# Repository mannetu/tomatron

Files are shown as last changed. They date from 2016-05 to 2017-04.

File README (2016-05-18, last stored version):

// Software SPI (slower updates, more flexible pin options):
// pin 7 - Serial clock out (SCLK)
// pin 6 - Serial data out (DIN)
// pin 5 - Data/Command select (D/C)
// pin 4 - LCD chip select (CS)
// pin 3 - LCD reset (RST)
//Adafruit_PCD8544 display = Adafruit_PCD8544(7, 6, 5, 4, 3);

// Hardware SPI (faster, but must use certain hardware pins):
// SCK is LCD serial clock (SCLK) - this is pin 13 on Arduino Uno
// MOSI is LCD DIN - this is pin 11 on an Arduino Uno
// pin 5 - Data/Command select (D/C)
// pin 4 - LCD chip select (CS)
// pin 3 - LCD reset (RST)
Adafruit_PCD8544 display = Adafruit_PCD8544(8, 7, 6);
// Note with hardware SPI MISO and SS pins aren't used but will still be read
// and written to during SPI transfer.  Be careful sharing these pins!

#define NUMFLAKES 10
#define XPOS 0
#define YPOS 1
#define DELTAY 2

#define LOGO16_GLCD_HEIGHT 16
#define LOGO16_GLCD_WIDTH  16

static const unsigned char PROGMEM logo16_glcd_bmp[] =
{ B00000000, B00000000,
 B00000000, B00000000,
 B00000000, B00000000,
 B00000000, B00000000,
 B00000000, B00000000,
 B00000000, B00000000,
 B00000000, B00000000,
 B00000000, B00000000,
 B00000000, B00000000,
 B00000000, B00000000,
 B00000000, B00000000,
 B00000000, B00000000,
 B00000000, B00000000,
 B00000000, B00000000,
 B00000000, B00000000,
 B00000000, B00000000 };

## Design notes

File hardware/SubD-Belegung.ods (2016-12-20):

Funktion | Kabel | Klemme | Atmega Pin | SubD pin
+5V | gelb | 1 | 7/20/21 | 4
GND | orange | 2 | 8/21 | 3
Valve 1 | braun | 3 | 11 | 1
Valve 2 | rot | 4 | 12 | 2
Valve 3 | weiss | 5 | 13 | 9
Valve 4 | schwarz | 6 | 14 | 10
Valve 5 | blau | 7 | 24 | 15
Valve 6 | grau | 8 | 25 | 8
Pump | rosa | 9 | 6 | 12
Flow | hellblau | 12 | 5 | 13
 |  | 10
 |  | 11
RX | petrol |  | 2 | 14
TX | hellgrün |  | 3 | 6
Reset | violet |  | 1 | 7
Button4 | türkis? |  | 23 | 5

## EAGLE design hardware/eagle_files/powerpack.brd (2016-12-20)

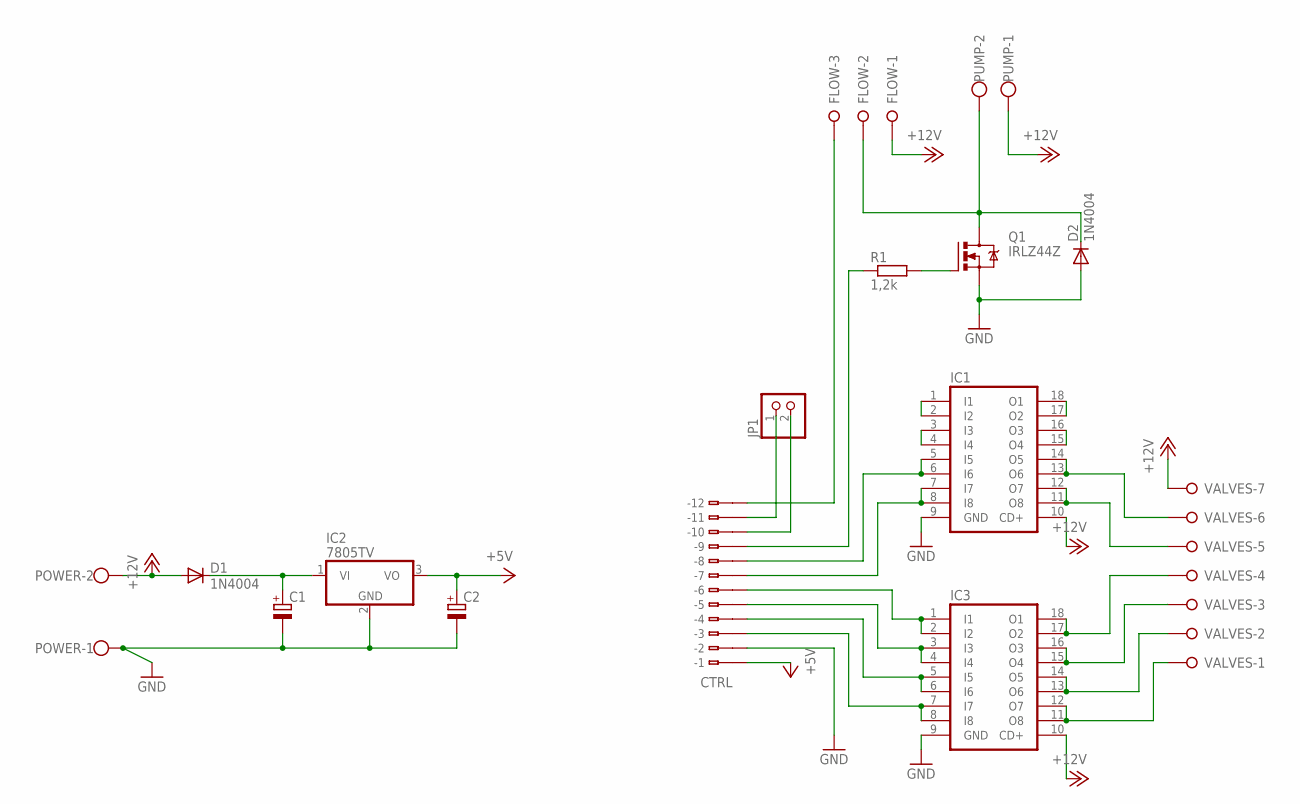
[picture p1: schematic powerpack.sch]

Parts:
C1, C2: CPOL-EUE2.5-7; E2,5-7
CTRL: 233-112
D1, D2: 1N4004; DO41-10
FLOW: W237-03P; W237-133
IC1, IC3: ULN2803A; DIL18
IC2: 7805TV; TO220V
JP1: PINHD-1X2; 1X02
POWER: W237-102
PUMP: W237-102
Q1: IRLZ44Z; TO220BH
R1: 1,2k; 0207/10
VALVES: W237-07P; W237-7P

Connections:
+5V: C2.+, CTRL.B1 (B-1), IC2.3 (VO)
+12V: D1.A, FLOW.1, IC1.10 (CD+), IC3.10 (CD+), POWER.2, PUMP.1, VALVES.7
GND: C1.-, C2.-, CTRL.B2 (B-2), D2.A, IC1.9 (GND), IC2.2 (GND), IC3.9 (GND), POWER.1, Q1.S
unnamed: C1.+, D1.C, IC2.1 (VI)
unnamed: CTRL.B12 (B-12), FLOW.3
unnamed: CTRL.B11 (B-11), JP1.1
unnamed: CTRL.B10 (B-10), JP1.2
unnamed: IC1.1 (I1), IC1.2 (I2)
unnamed: IC1.3 (I3), IC1.4 (I4)
unnamed: CTRL.B8 (B-8), IC1.5 (I5), IC1.6 (I6)
unnamed: CTRL.B7 (B-7), IC1.7 (I7), IC1.8 (I8)
unnamed: IC1.17 (O2), IC1.18 (O1)
unnamed: IC1.15 (O4), IC1.16 (O3)
unnamed: IC1.13 (O6), IC1.14 (O5), VALVES.6
unnamed: IC1.11 (O8), IC1.12 (O7), VALVES.5
unnamed: Q1.G, R1.2
unnamed: D2.C, FLOW.2, PUMP.2, Q1.D
unnamed: IC3.17 (O2), IC3.18 (O1), VALVES.4
unnamed: IC3.15 (O4), IC3.16 (O3), VALVES.3
unnamed: IC3.13 (O6), IC3.14 (O5), VALVES.2
unnamed: IC3.11 (O8), IC3.12 (O7), VALVES.1
unnamed: CTRL.B3 (B-3), IC3.7 (I7), IC3.8 (I8)
unnamed: CTRL.B4 (B-4), IC3.5 (I5), IC3.6 (I6)
unnamed: CTRL.B5 (B-5), IC3.3 (I3), IC3.4 (I4)
unnamed: CTRL.B6 (B-6), IC3.1 (I1), IC3.2 (I2)
unnamed: CTRL.B9 (B-9), R1.1

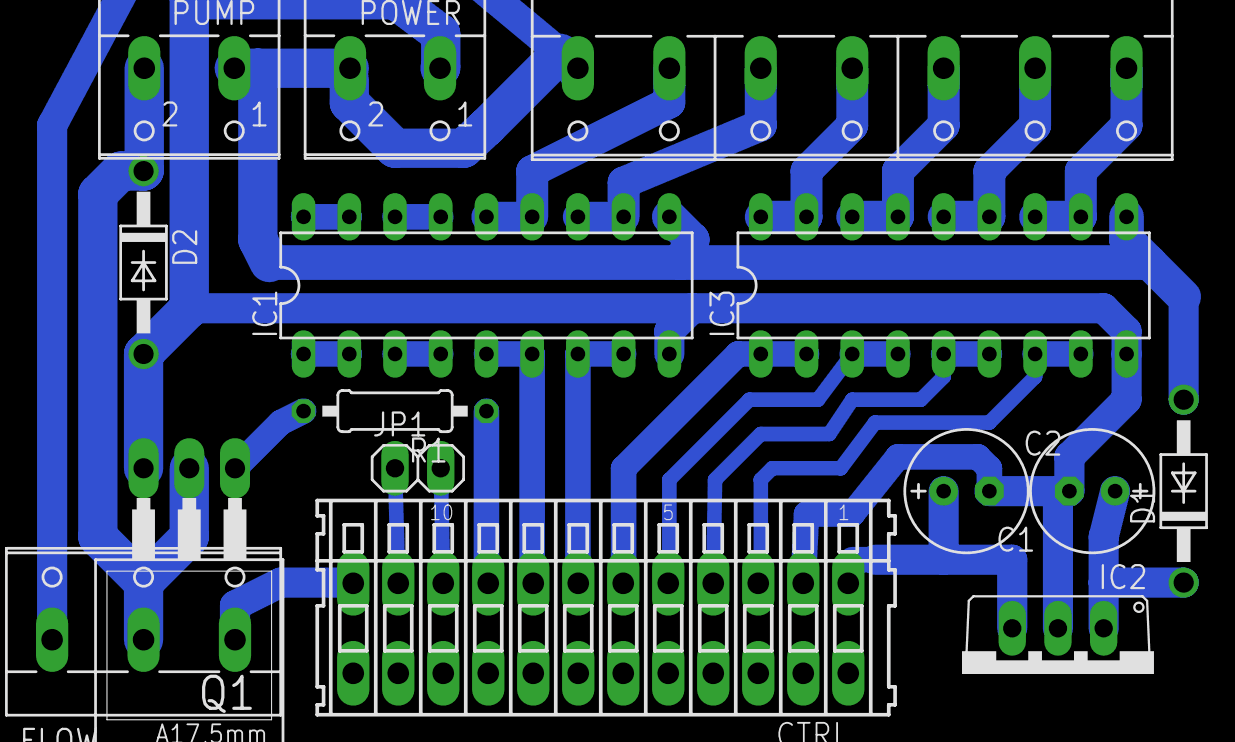
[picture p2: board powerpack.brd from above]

Board: 2 copper layers, 15 parts (0 on the bottom side), 26 nets.

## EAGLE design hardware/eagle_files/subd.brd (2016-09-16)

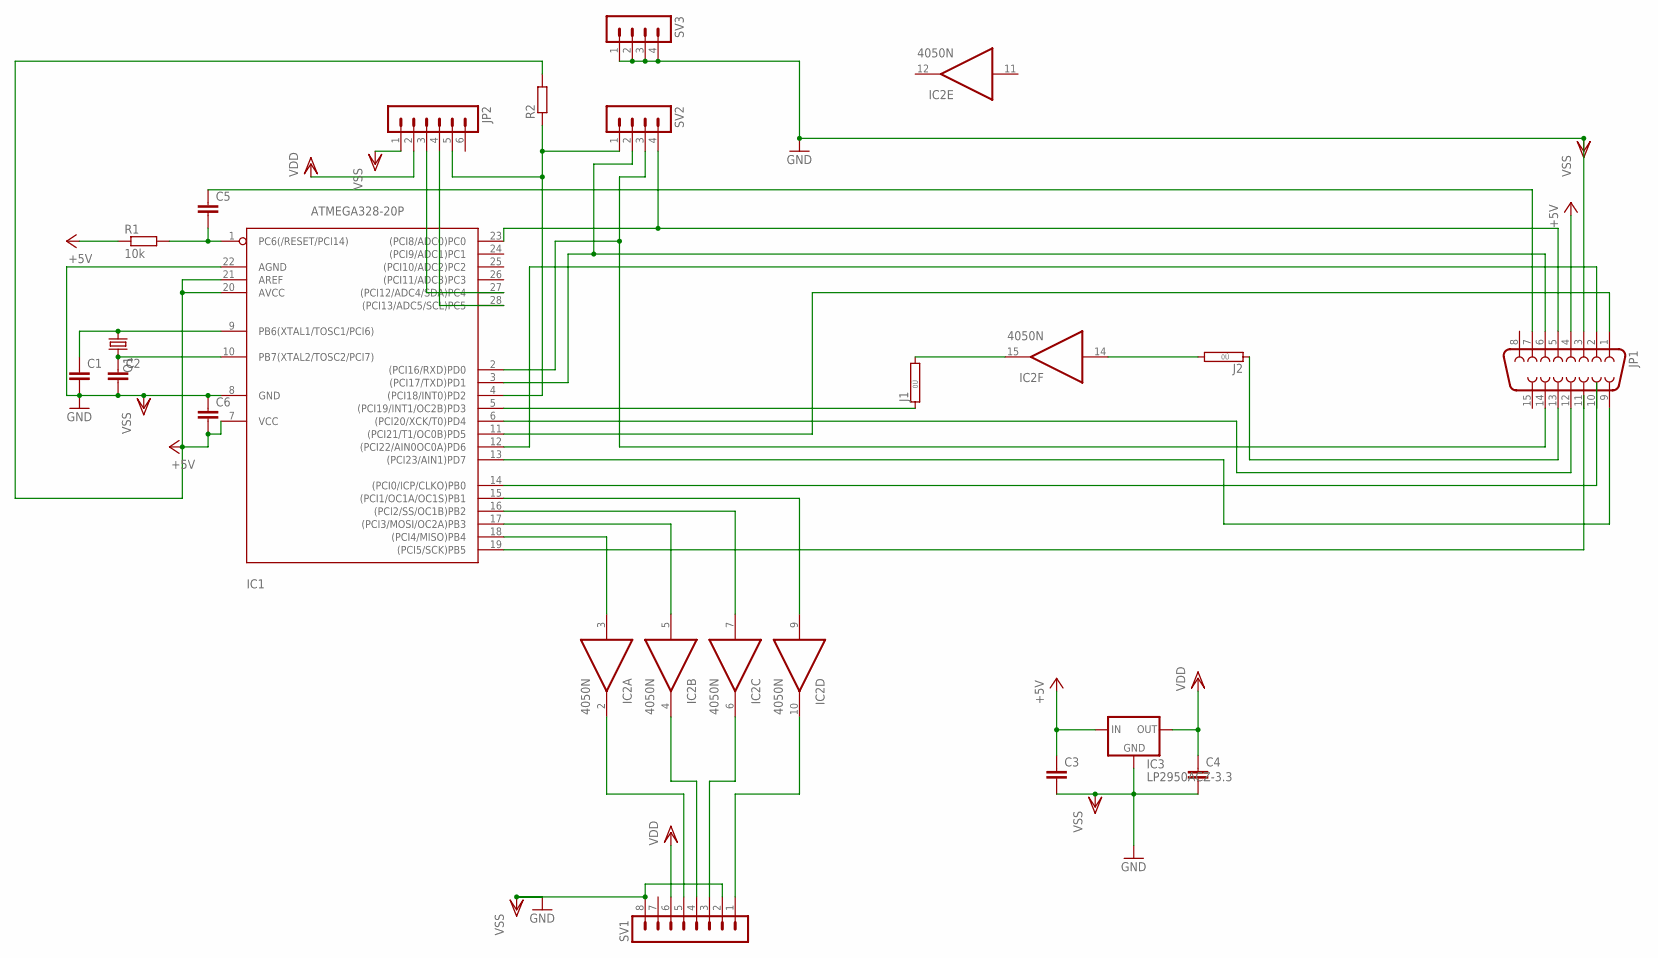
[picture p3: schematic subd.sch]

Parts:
C1, C2, C5, C6: C5/3; C5B3
C3, C4: C2.5/5; C2.5-5
IC1: ATMEGA328-20P; DIL28-3
IC2: 4050N; DIL16
IC3: LP2950ACZ-3.3; TO92
J1, J2: 0R; 0R/10
JP1: F15H
JP2: MA06-1
Q1: CRYSTALHC18U-V; HC18U-V
R1: 10k; 0207/12
R2: R-EU_0207/10; 0207/10
SV1: MA08-1
SV2, SV3: MA04-1

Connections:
+5V: C3.1, C6.2, IC1.7 (VCC), IC1.20 (AVCC), IC1.21 (AREF), IC3.3 (IN), JP1.4, R1.1, R2.2
unnamed: C1.1, IC1.9 (PB6(XTAL1/TOSC1/PCI6)), Q1.1
unnamed: C2.1, IC1.10 (PB7(XTAL2/TOSC2/PCI7)), Q1.2
unnamed: IC1.14 ((PCI0/ICP/CLKO)PB0), JP1.10
unnamed: IC1.13 ((PCI23/AIN1)PD7), JP1.9
unnamed: IC1.15 ((PCI1/OC1A/OC1S)PB1), IC2.9 (I)
unnamed: IC1.16 ((PCI2/SS/OC1B)PB2), IC2.7 (I)
unnamed: IC1.17 ((PCI3/MOSI/OC2A)PB3), IC2.5 (I)
unnamed: IC1.18 ((PCI4/MISO)PB4), IC2.3 (I)
unnamed: IC2.2 (O), SV1.5
unnamed: IC2.4 (O), SV1.4
unnamed: IC2.6 (O), SV1.3
unnamed: IC2.10 (O), SV1.1
unnamed: IC1.12 ((PCI22/AIN0OC0A)PD6), JP1.2
unnamed: IC1.11 ((PCI21/T1/OC0B)PD5), JP1.1
unnamed: IC1.6 ((PCI20/XCK/T0)PD4), JP1.12
unnamed: IC1.5 ((PCI19/INT1/OC2B)PD3), J1.1
unnamed: C5.1, JP1.7
unnamed: C5.2, IC1.1 (PC6(/RESET/PCI14)), R1.2
unnamed: IC1.27 ((PCI12/ADC4/SDA)PC4), JP2.3
unnamed: IC1.28 ((PCI13/ADC5/SCL)PC5), JP2.4
unnamed: IC1.4 ((PCI18/INT0)PD2), JP2.5, R2.1, SV2.1
unnamed: IC1.3 ((PCI17/TXD)PD1), JP1.6, SV2.2
unnamed: IC1.2 ((PCI16/RXD)PD0), JP1.14, SV2.3
unnamed: IC2.14 (I), J2.2
unnamed: IC1.23 ((PCI8/ADC0)PC0), JP1.5, SV2.4
unnamed: IC2.15 (O), J1.2
unnamed: J2.1, JP1.13
unnamed: IC1.19 ((PCI5/SCK)PB5), JP1.11
VDD: C4.1, IC2.1 (VDD), IC3.1 (OUT), JP2.2, SV1.6
VSS: C1.2, C2.2, C3.2, C4.2, C6.1, IC1.8 (GND), IC1.22 (AGND), IC2.8 (VSS), IC3.2 (GND), JP1.3, JP2.1, SV1.2, SV1.8, SV3.1, SV3.2, SV3.3, SV3.4

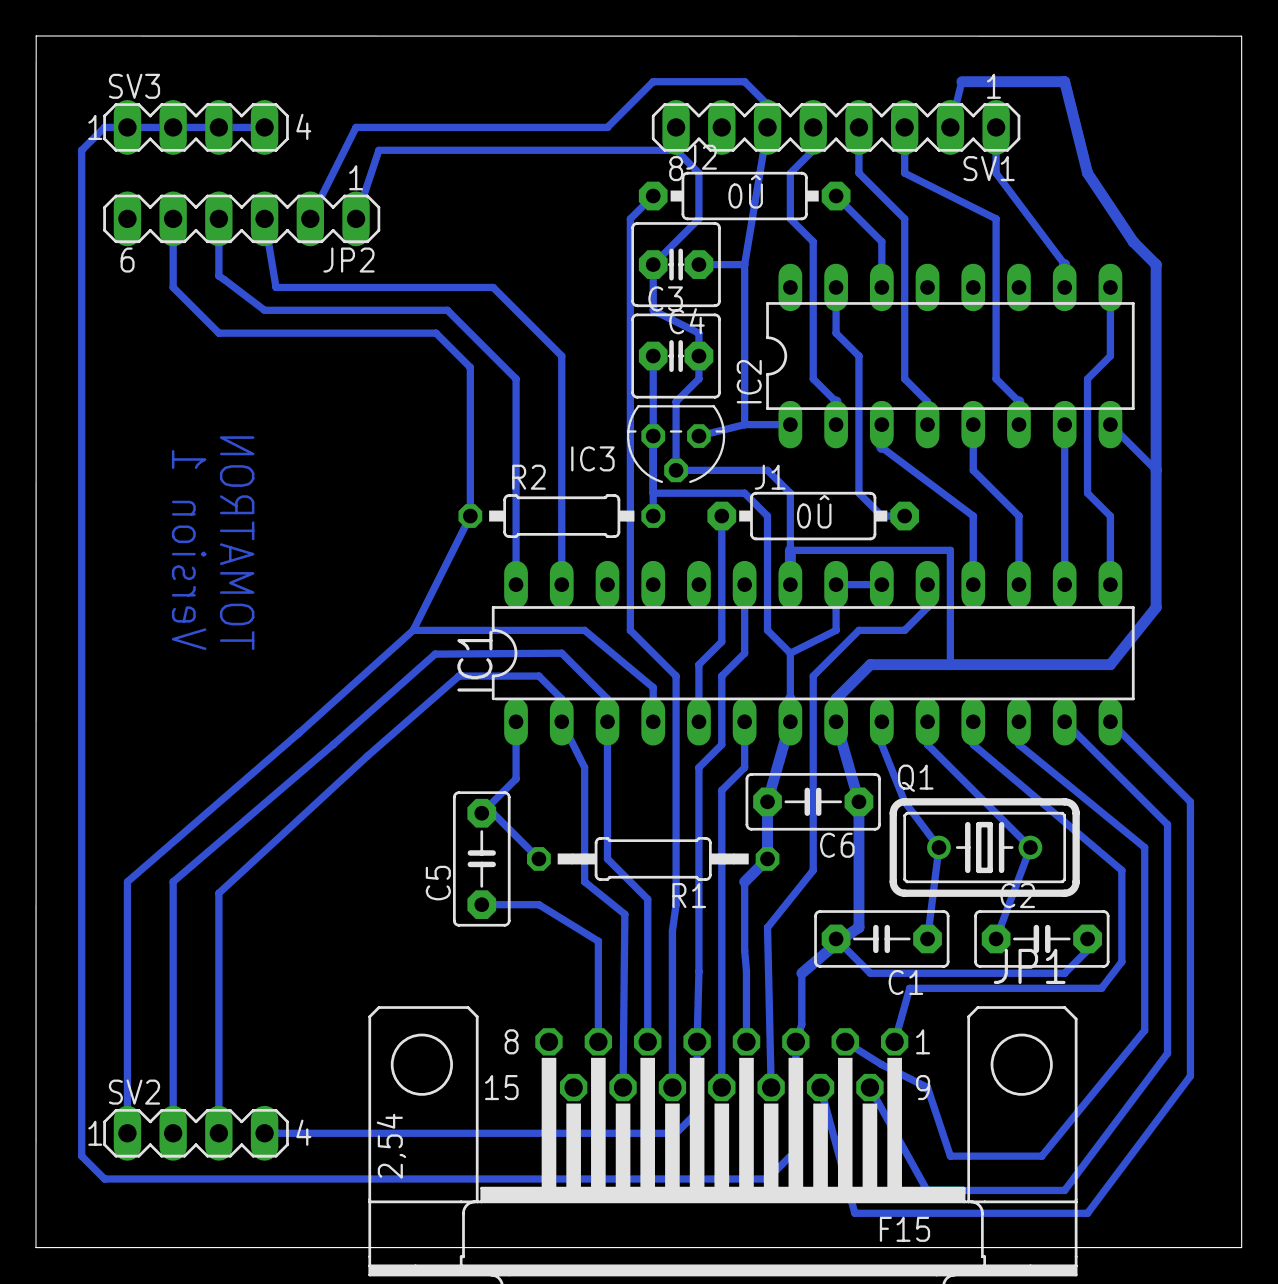
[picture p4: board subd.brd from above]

Board: 2 copper layers, 67.0 x 67.3 mm, 19 parts (0 on the bottom side), 31 nets.

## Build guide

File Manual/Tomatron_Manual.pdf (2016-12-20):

# T O M A T R O N

## Installation

&

## Bedienungsanleitung

Version 1.0

Das Kleingedruckte:
Der Hersteller übernimmt keine Haftung für vertrocknete Tomaten, Paprika, etc.

## Installation der Schalteinheit

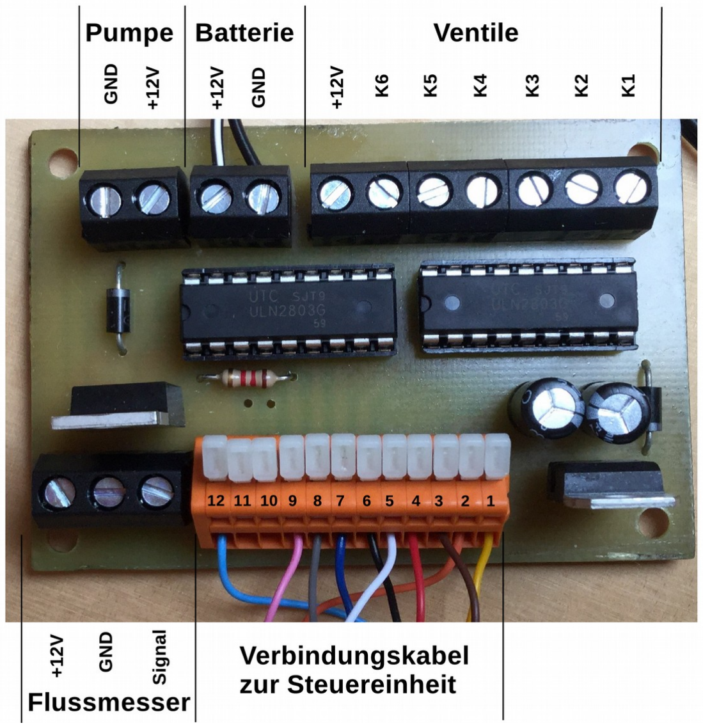
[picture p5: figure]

1. Pumpe anklemmen. Maximale Stromaufnahme der Pumpe ist xA.
2. Batterie über beigelegte Sicherung (xA) anklemmen. Auf Polung achten!
3. Kabels zur Steuereinheit an der orangen Klemmleiste nach Farben anklemmen:
Funktion | Litzenfarbe | Klemme
+5V | gelb | 1
GND | orange | 2
Ventil 1 | braun | 3
Ventil 2 | rot | 4
Ventil 3 | weiss | 5
Ventil 4 | schwarz | 6
Ventil 5 | dunkelblau | 7
Ventil 6 | grau | 8
Pumpe | rosa | 9
nicht belegt | | 10
nicht belegt | | 11
Flowmeter Signal | hellblau | 12
4. Ventile an gemeinsame Klemme für +12V und Klemmen K1 bis K6 anschliessen. Maximale Stromaufnahme pro Ventil ist xA.
5. Flussmessers an +12V (rotes Kabel), GND (schwarzes Kabel) und Signal (gelbes Kabel) anklemmen.

## Installation der Bedieneinheit und Bedienelemente

## Inbetriebnahme

Kalibrierung des Flussmessers
Zur genauen Dosierung muss der Flussmesser bei Inbetriebnahme kalibriert werden. Hierfür muss die Taste MENU während des Anklemmens der Stromversorgung kurzzeitig gehalten werden. Nach einem weiteren Betätigen der Taste MENU werden über Ventil 1 circa 10 L Wasser dosiert. Die genaue Menge ist im Anschluss auszuwiegen und mit den Tasten + und − einzustellen. Die Kalibrierung wird mit der Taste MENU abgeschlossen.

Einstellen der Uhrzeit
Zum Einstellen der Uhrzeit nach muss die Taste MENU wiederholt gedrückt werden bis die Anzeige der Uhrzeit dunkel hinterlegt angezeigt wird.
Die Uhrzeit ist nun durch Halten der Tasten + und − einzustellen.
Wenn die gewünschte Uhrzeit angezeigt wird, kann die Einstellung mit einem weiteren Betätigen der Taste MENU abgeschlossen werden oder gewartet werden bis die Anzeige einigen Sekunden von selbst in den Normalmodus zurückspringt.

## Einstellungen

Einstellen der Giessmengen
Zum Einstellen der Giessmengen muss die Taste MENU gedrückt werden bis der jeweilige Giesskanal dunkel hinterlegt angezeigt wird. Die Menge ist nun durch Halten der Tasten + und − einzustellen. Wenn die gewünschte Uhrzeit angezeigt wird, kann mit einem weiteren Betätigen der Taste MENU zum nächsten Kanal gewechselt werden. Sind alle Einstellungen getätigt springt die Anzeige einigen Sekunden von selbst in den Normalmodus zurück. Einstellen der Giesszeit
Zum Einstellen der Giesszeit nach muss die Taste MENU wiederholt gedrückt werden bis die Anzeige der Giesszeit dunkel hinterlegt angezeigt wird.
Die Giesszeit ist nun durch Halten der Tasten + und − einzustellen.
Wenn die gewünschte Giesszeit angezeigt wird, kann mit einem weiteren Betätigen der Taste MENU zur Einstellung des Giessfaktors gewechselt werden. Ohne Tastendruck springt die Anzeige nach ein einigen Sekunden von selbst in den Normalmodus zurück.

Einstellen des Giesskoeffizient f
Die Steuereinheit zeichnet von 8 Uhr morgens bis zur eingestellten Giesszeit minütlich die Temperatur auf und bildet hieraus den Tagesmittelwert der Temperatur. Dieser wird aktuell im Display angezeigt.
In Abhängigkeit des errechneten Temperaturmittelwertes und eines einzustellenden Giesskoeffizienten f werden die vorgegebnen Giessmengen pro Kanal mit einem Giessfaktor multipliziert der sich aus dem Diagramm ergibt. Zum Einstellen des Giesskoeffizients f muss die Taste MENU gedrückt werden bis das Feld dunkel hinterlegt angezeigt wird. Der Wert ist nun durch Halten der Tasten + und − einzustellen. Die Anzeige springt ohne Tastendruck nach einigen Sekunden von selbst in den Normalmodus zurück.

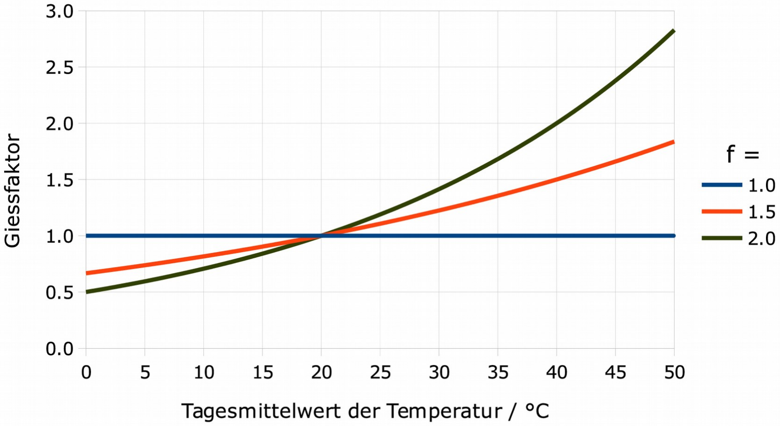
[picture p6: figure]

Beispiele: Bei einem Tagesmittelwert von 30 °C und f = 2.0 wird das 1,4-fache der voreingestellten Mengen dosiert. Bei einem Tagesmittelwert von 40 °C und f = 1,5 wird das 1,5-fache dosiert.

Funktion Kabel | Klemme Atmega Pin SubD pin
+5V | gelb | 1 | 7/20/21 | 4
GND | orange | 2 | 8/21 | 3
Valve 1 | braun | 3 | 11 | 1
Valve 2 | rot | 4 | 12 | 2
Valve 3 | weiss | 5 | 13 | 9
Valve 4 | schwarz | 6 | 14 | 10
Valve 5 | blau | 7 | 24 | 15
Valve 6 | grau | 8 | 25 | 8
Pump | rosa | 9 | 6 | 12
Flow | hellblau | 12 | 5 | 13
| | 10
| | 11
RX | petrol | | 2 | 14
TX | hellgrün | | 3 | 6
Reset | violet | | 1 | 7
Button4 | türkis? | | 23 | 5

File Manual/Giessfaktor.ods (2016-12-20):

Temperatur | 1.0 | 1.5 | 2.0
0 | 1.0 | 0.7 | 0.50
1 | 1.0 | 0.7 | 0.52
2 | 1.0 | 0.7 | 0.54
3 | 1.0 | 0.7 | 0.55
4 | 1.0 | 0.7 | 0.57
5 | 1.0 | 0.7 | 0.59
6 | 1.0 | 0.8 | 0.62
7 | 1.0 | 0.8 | 0.64
8 | 1.0 | 0.8 | 0.66
9 | 1.0 | 0.8 | 0.68
10 | 1.0 | 0.8 | 0.71
11 | 1.0 | 0.8 | 0.73
12 | 1.0 | 0.9 | 0.76
13 | 1.0 | 0.9 | 0.78
14 | 1.0 | 0.9 | 0.81
15 | 1.0 | 0.9 | 0.84
16 | 1.0 | 0.9 | 0.87
17 | 1.0 | 0.9 | 0.90
18 | 1.0 | 1.0 | 0.93
19 | 1.0 | 1.0 | 0.97
20 | 1.0 | 1.0 | 1.00
21 | 1.0 | 1.0 | 1.04
22 | 1.0 | 1.0 | 1.07
23 | 1.0 | 1.1 | 1.11
24 | 1.0 | 1.1 | 1.15
25 | 1.0 | 1.1 | 1.19
26 | 1.0 | 1.1 | 1.23
27 | 1.0 | 1.2 | 1.27
28 | 1.0 | 1.2 | 1.32
29 | 1.0 | 1.2 | 1.37
30 | 1.0 | 1.2 | 1.41
31 | 1.0 | 1.2 | 1.46
32 | 1.0 | 1.3 | 1.52
33 | 1.0 | 1.3 | 1.57
34 | 1.0 | 1.3 | 1.62
35 | 1.0 | 1.4 | 1.68
36 | 1.0 | 1.4 | 1.74
37 | 1.0 | 1.4 | 1.80
38 | 1.0 | 1.4 | 1.87
39 | 1.0 | 1.5 | 1.93
40 | 1.0 | 1.5 | 2.00
41 | 1.0 | 1.5 | 2.07
42 | 1.0 | 1.6 | 2.14
43 | 1.0 | 1.6 | 2.22
44 | 1.0 | 1.6 | 2.30
45 | 1.0 | 1.7 | 2.38
46 | 1.0 | 1.7 | 2.46
47 | 1.0 | 1.7 | 2.55
48 | 1.0 | 1.8 | 2.64
49 | 1.0 | 1.8 | 2.73
50 | 1.0 | 1.8 | 2.83

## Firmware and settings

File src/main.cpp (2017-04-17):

/***********************************************
*  Tomatron v2.0
*
*
***********************************************/

#include <Arduino.h>
#include <EEPROM.h>
#include <Time.h>
#include <avr/wdt.h>  // Watchdog-Timer
#include <avr/sleep.h>
#include <avr/power.h>
#include <Wire.h>
#include <DS3232RTC.h>
#include <Adafruit_GFX.h>
#include <Adafruit_PCD8544.h>
#include "water.h"

//---------------------------------------------------------
// System Setup
//---------------------------------------------------------

#define CHANNEL 6  // Number of water channels

// Giessflag
enum giessFlag {
  CTRL_SLEEP = -3,
  CTRL_SET   = -2,
  CTRL_IDLE  = -1,
  CTRL_ACT   =  0  // 1, 2, 3
};

enum timerFlag {
  OFF,
  ON
} timer;

struct s_giess {
  int    flag     = -1;
  long   lastCall =  0;
  time_t time;
} giess;

//---------------------------------------------------------
// Display
//---------------------------------------------------------
// Nokia 5110 Adafruit Library
// Software SPI (slower updates, more flexible pin options):
// pin 12 - Serial clock out (SCLK)
// pin 11 - Serial data out (DIN)
// pin 10 - Data/Command select (D/C)
// GND    - LCD chip select (CS)
// pin 9 - LCD reset (RST)

Adafruit_PCD8544 display = Adafruit_PCD8544(12, 11, 10, 9);
#define DISPLAY_UPDATE 250  // Display update rate (milliseconds)

//---------------------------------------------------------
// Buttons
//---------------------------------------------------------
const byte pinUpBtn =     0;   // Up-Button, ATmega pin 2
const byte pinDownBtn =   A0;   // Down-Button, ATmega pin 3
const byte pinEnterBtn =  2;   // Enter-Button, Interupt 0, ATmega pin 4
const byte pinManualBtn = 1; // Manual-Button, ATmega pin 23

unsigned int btnDelay =   200; // Debounce delay

//---------------------------------------------------------
// Objects
//---------------------------------------------------------
Flowmeter flow(3); // Interupt 1 -> Pin 3 must not be changed! // ATmega pin 5

Magnetvalves valve[CHANNEL] =
{  // 8 characters max.
  Magnetvalves(5,  "Tom1  "),  // ATmega pin 11
  Magnetvalves(6,  "Tom2  "),  // ATmega pin 12
  Magnetvalves(7,  "Tom3  "),  // ATmega pin 13
  Magnetvalves(8,  "Pap1  "),  // ATmega pin 14
  Magnetvalves(A1, "Pap2  "),  // ATmega pin 24
  Magnetvalves(A2, "Gur1  ")   // ATmega pin 25
};

Pump pump(4); // ATmega pin 6

Thermocontrol thermo(8); // Daytime hour to start temperature averaging

volatile boolean alarmIsrWasCalled = true;

//---------------------------------------------------------
// Function prototypes
//---------------------------------------------------------

int   checkGiessen(void);
void  giessRoutine(void);
void  manualGiess(int);
void  statusDisplay(int, int);

void  interruptPulse(void);

void  setParameters(void);
void  writeParameters();

void  btnInterruptSleep(void);
void  enterSleep(void);

void  calibration();
void  calibrationDoseDisplay(int);
void  calibrationDisplay(double);


//-------------------------------------------------------------------
//-------------------------------------------------------------------
// SETUP
//-------------------------------------------------------------------
void setup()
{
/*** ONLY FOR INITIAL EEPROM AND RTC PROGRAMMING *******************
  // Giesstime
    setTime(18, 30, 00, 01, 05, 16); // hour, min, sec, day, month, year
    RTC.set(now());
    giess.time = now() + 3600;
    int eepromAdress = 0;
    EEPROM.put(0, giess.time);
    eepromAdress += sizeof(time_t);

  // Flow Calibration Factor
      EEPROM.put(eepromAdress, 480); // Datasheet says 480 Pulses/L
      eepromAdress += sizeof(int);

  // thermoCoeff
      float thermoCoeff = 1.5;
      EEPROM.put(eepromAdress, thermoCoeff);
********************************************************************/

  // Power management
  power_adc_disable();
  power_spi_disable();
  power_timer1_disable();
  power_timer2_disable();

  // Setup the Watchdog Timer
  wdt_enable(WDTO_8S);

  // Setup LCD display
  display.begin(); // init done
  display.setContrast(50);
  display.setRotation(2);
  display.setTextSize(1);
  display.setTextColor(BLACK);
  delay(1000);

  // Set time and RTC options
  while (RTC.get() == 0);
  setTime(RTC.get());   // the function to get the time from the RTC

  /* Set RTC alarm to wake-up microcontroller every minute
  * Alarm pin of RTC is attached to Pin 2 (EnterButton)  */
  RTC.squareWave(SQWAVE_NONE);
  RTC.alarm(ALARM_1);
  RTC.alarmInterrupt(ALARM_1, false);
  RTC.setAlarm(ALM2_EVERY_MINUTE, 1, 1, 1, 1);
  RTC.alarm(ALARM_2);
  RTC.alarmInterrupt(ALARM_2, true);

  // Set pin configuration for buttons
  pinMode(pinEnterBtn, INPUT);   //external pull-up resistor required due to interrupt function!!
  pinMode(pinUpBtn, INPUT_PULLUP);
  pinMode(pinDownBtn, INPUT_PULLUP);
  pinMode(pinManualBtn, INPUT_PULLUP);
  flow.resetFlowMeter();

  // Read giessTime from EEPROM
  int eeAdress = 0;
  EEPROM.get(eeAdress, giess.time);
  eeAdress += sizeof(time_t); // Move write position to calibration factor

  // Initialize GiessFlag
  giess.flag = CTRL_IDLE;
  timer = OFF;

  // Read calibration factor from EEPROM
  int cf;
  EEPROM.get(eeAdress, cf);
  flow.setCalibrationFactor(cf);
  eeAdress += sizeof(int); // Move write position to temperature factor

  // Read temperature factor factor from EEPROM
  float tf;
  EEPROM.get(eeAdress, tf);
  thermo.SetTempCoeff(tf);
  eeAdress += sizeof(float); // Move write position to volume targets

  // Read volume targets from EEPROM
  int vol;
  for (byte i = 0; i < (CHANNEL); i++) {
    EEPROM.get(eeAdress, vol);  //
    eeAdress += sizeof(int); // Set position to next vol target
    valve[i].setVolumeTarget(vol);
  }

  // If Enter is pressed at boot, enter calibration mode
  if (digitalRead(pinEnterBtn) == LOW) {
    display.clearDisplay();
    display.display();
    delay(2000);
    calibration();
  }
  statusDisplay(-1, -1);
}


//--------------------------------------------------------------
// Function name: loop()
//--------------------------------------------------------------
void loop()
{
  // If nothing happens
  if(giess.flag == CTRL_IDLE)
  {
    // MCU enter sleep
    statusDisplay(CTRL_SLEEP, -1);
    wdt_disable();
    enterSleep();

    // Continue after wake-up
    wdt_enable(WDTO_8S); // Enable Watchdog-Timer
    setTime(RTC.get()); // Update MCU time from RTC
    if (hour() > (thermo.GetLowerAveragingHour()-1) &&
        (hour() < hour(giess.time) || (hour() == hour(giess.time) &&
          minute() < minute(giess.time))))
    {
      thermo.AddTempReading(RTC.temperature()/float(4.0)); // Temperature measurement
    }
    statusDisplay(CTRL_IDLE, -1);
  }

  // Reset RTC alarm
  if (alarmIsrWasCalled)
  {
    RTC.alarm(ALARM_2);
    alarmIsrWasCalled = false;
  }

  // Check if it is time for giessing */
  if (timer == ON && giess.flag == CTRL_IDLE)
  {
    giess.flag = checkGiessen();
  }

  // Update Display every DISPLAY_UPDATE ms*/
  if ((millis() - giess.lastCall > DISPLAY_UPDATE))
  {
    statusDisplay(giess.flag, -1);
    giess.lastCall = millis();
  }

  // If giessing, then check progress */
  if (giess.flag > CTRL_IDLE) // that is active channel 0, 1, 2, or 3
  {
    valve[giess.flag].setGiessFactor(thermo.GetGiessFactor());
    giessRoutine();
  }

  // On enter btn press, start mode to set time, giessTime and target volumes */
  if (digitalRead(pinEnterBtn) == 0)
  {
    RTC.alarmInterrupt(ALARM_2, false);
    setParameters();
    if (giess.flag == CTRL_IDLE)
    {
      RTC.alarm(ALARM_2);
      RTC.alarmInterrupt(ALARM_2, true);
    }
  }

  wdt_reset();
}


//--------------------------------------------------------------
// Function name: checkGiessen
//
// checks if it is time for giessen
//--------------------------------------------------------------
int checkGiessen()
{
  if ((hour(giess.time) == hour()) && (minute(giess.time) == minute()))
  {
    flow.resetFlowMeter();
    RTC.alarmInterrupt(ALARM_2, false);
    return CTRL_ACT;
  }
  return CTRL_IDLE;
}


//--------------------------------------------------------------
// Function name: giessRoutine
//--------------------------------------------------------------
void giessRoutine()
{
  if (pump.start()) delay(1000); // wait for 2s if pump had to be started

  valve[giess.flag].setCurrentVolume(flow.getVolume());

  if (valve[giess.flag].dosing() == 0)
  {
    flow.resetFlowMeter();
    giess.flag++; delay(100);
  }

  if (giess.flag > CHANNEL-1)
  {
    pump.stop();
    thermo.ResetAverage();
    giess.flag = CTRL_IDLE;
    RTC.alarm(ALARM_2);
    RTC.alarmInterrupt(ALARM_2, true);
  }
}

//--------------------------------------------------------------
// Function name: manualGiess
//--------------------------------------------------------------
void manualGiess(int ch)
{
  pump.start();
  delay(500);
  giess.flag = ch;
  flow.resetFlowMeter();
  valve[ch].open();
  while (digitalRead(pinManualBtn) != 0 && digitalRead(pinEnterBtn) != 0)
  {
    valve[giess.flag].setCurrentVolume(flow.getVolume());
    if ((millis() - giess.lastCall > DISPLAY_UPDATE))
    {
      statusDisplay(giess.flag, -5);
      giess.lastCall = millis();
    }
    wdt_reset();
  }
  valve[ch].close();
  pump.stop();
  giess.flag = CTRL_IDLE;

  // Show instructions on display
  display.clearDisplay();
  display.setCursor(14,6);
  display.print(valve[ch].getPlantName());
  display.setCursor(44,6);
  display.print(flow.getVolume(), 0);
  display.println(" L");
  display.setCursor(0,17);
  display.println("  Neue Menge ");
  display.println(" uebernehmen?");
  display.setCursor(0,36);
  display.println("   +/- = ja");
  display.display();

  delay(3*btnDelay);

  long lastActivity;
  lastActivity = millis();

  while (digitalRead(pinEnterBtn) != 0 && digitalRead(pinManualBtn) != 0)
  {
    if (digitalRead(pinUpBtn) == 0 || digitalRead(pinDownBtn) == 0)
    {
      valve[ch].setVolumeTarget(flow.getVolume());
      wdt_reset();
      writeParameters();
      delay(btnDelay);
      return;
    }
    wdt_reset();
    if (millis() - lastActivity > 5000) return;
  }
  delay(btnDelay);
  return;
}

//--------------------------------------------------------------
// Status Display
//--------------------------------------------------------------
void statusDisplay(int gf, int ch)
{
  static byte blink_flag = 1;
  display.clearDisplay();
  display.setCursor(0, 0);

  //---------------------------------------------------
  // Display if nothing is active or parameter set mode

  if (gf < 0)    //  -1 or -2
  {
    if (gf == -2 && ch == -2) display.setTextColor(WHITE, BLACK);

    // Draw grid
    display.drawFastHLine(0, 9, 85, BLACK);
    display.drawFastHLine(41, 30, 43, BLACK);
    display.drawFastVLine(40, 0, 48, BLACK);

    // Print current time
    if(hour() < 10) display.print(' ');
    display.print(hour());
    display.print(":");
    if(minute() < 10) display.print('0');
    display.print(minute());
    display.setTextColor(BLACK, WHITE);

    // Print giessFactor
    display.setCursor(47, 33);
    if (gf == -2 && ch == -3)
    {
      display.setTextColor(WHITE, BLACK);
      display.print("f");
      display.print(thermo.GetTempCoeff(), 1);
      display.setTextColor(BLACK, WHITE);
    }
    else
    {
      display.print("x");
      display.print(thermo.GetGiessFactor(), 1);
    }

    // Print average temperature
    display.setCursor(47, 41);
    if (thermo.GetTempAverage() > 0)
    {
      display.print(thermo.GetTempAverage(), 1);
    }
    else
    {
      display.print("---");
    }
    display.print("C");

    // Print giess time
    display.setCursor(44, 0);
    if (timer == ON)
    {
      if (gf == -2 && ch == -1) display.setTextColor(WHITE, BLACK);
      display.print("T ");
      display.setCursor(52, 0);
      if(hour(giess.time) < 10) display.print(' ');
      display.print(hour(giess.time));
      display.print(":");
      if(minute(giess.time) < 10) display.print('0');
      display.print(minute(giess.time));
      display.setTextColor(BLACK, WHITE);
    }
    else
    {
      if (gf == -2 && ch == -1) display.setTextColor(WHITE, BLACK);
      display.print("T aus");
      display.setTextColor(BLACK, WHITE);
    }

    // Print channels, left column
    for (int i = 0; i < 4; i++)
    {
      display.setCursor(0, (8*i + 13));
      if (gf == -2 && i == ch) display.setTextColor(WHITE, BLACK);
      display.print(valve[i].getPlantName());
      display.setCursor(26, (8*i + 13));
      if (valve[i].readVolumeTarget()<10) display.print(" ");
      display.println(valve[i].readVolumeTarget());
      display.setTextColor(BLACK, WHITE);
    }

    // Print channels, right column
    for (int i = 4; i < CHANNEL; i++)
    {
      display.setCursor(44, (8*(i-4) + 13));
      if (gf == -2 && i == ch) display.setTextColor(WHITE, BLACK);
      display.print(valve[i].getPlantName());
      display.setCursor(70, (8 *(i-4) + 13));
      if (valve[i].readVolumeTarget()<10) display.print(" ");
      display.println(valve[i].readVolumeTarget());
      display.setTextColor(BLACK, WHITE);
    }

    display.display(); // show screen
    return;
  }

  //----------------------------------------------------
  // Display during active giessing

  if (gf > -1)
  {
    // Draw grid
    display.drawFastHLine( 0, 9,85, BLACK);
    display.drawFastHLine(41,30,43, BLACK);
    display.drawFastVLine(40,10,38, BLACK);

    // Blinking title (top box)
    if (blink_flag++ < 3) display.setTextColor(WHITE, BLACK);
    else display.setTextColor(BLACK, WHITE);
    display.setCursor(17,0);
    display.print(" WASSER ");
    blink_flag %= 5;

    // Current volume (box bottom right)
    display.setTextColor(BLACK, WHITE);
    display.setCursor(45,36);
    if (valve[gf].readCurrentVolume() < 10) display.print(" ");
    display.print(valve[gf].readCurrentVolume(), 1);
    display.print(" L");

    // Channels, left column
    for (int i = 0; i < 4; i++)
    {
      if (i == gf) // Display active channel
      {
        display.setTextColor(WHITE, BLACK);
        display.setCursor(0, (8*i+13));
        display.print(valve[i].getPlantName());
        display.setCursor(26, (8*i+13));
        if (ch == -5) display.println(" M");
        else
        {
          if (round(valve[i].readVolumeTarget() * thermo.GetGiessFactor()) < 10) display.print(" ");
          display.println(round(valve[i].readVolumeTarget() * thermo.GetGiessFactor()));
        }
        display.setTextColor(BLACK, WHITE);
      }
      else // Display idle channel
      {
        display.setCursor(0, (8*i+13));
        display.print(valve[i].getPlantName());
        display.setCursor(26, (8*i+13));
        if (round(valve[i].readVolumeTarget() * thermo.GetGiessFactor()) < 10) display.print(" ");
        display.println(round(valve[i].readVolumeTarget() * thermo.GetGiessFactor()));
      }
    }

    // Channels, right column
    for (int i = 4; i < CHANNEL; i++)
    {
      if (i == gf) // Display active channel
      {
        display.setTextColor(WHITE, BLACK);
        display.setCursor(44, (8*(i-4)+13));
        display.print(valve[i].getPlantName());
        display.setCursor(70, (8*(i-4)+13));
        if (ch == -5) display.println(" M");
        else
        {
          if (round(valve[i].readVolumeTarget() * thermo.GetGiessFactor()) < 10) display.print(" ");
          display.println(round(valve[i].readVolumeTarget() * thermo.GetGiessFactor()));
        }
        display.setTextColor(BLACK, WHITE);
      }
      else // Display idle channel
      {
        display.setCursor(44, (8*(i-4)+13));
        display.print(valve[i].getPlantName());
        display.setCursor(70, (8*(i-4)+13));
        if (round(valve[i].readVolumeTarget() * thermo.GetGiessFactor()) < 10) display.print(" ");
        display.println(round(valve[i].readVolumeTarget() * thermo.GetGiessFactor()));
      }
    }

    display.display(); // show screen
    return;
  }
}


//--------------------------------------------------------------
// Function name: interuptPulse()
//--------------------------------------------------------------
void interuptPulse()
{
  flow.pulse();
}


//-------------------------------------------------------------
//-------------------------------------------------------------
// SET MODE
//
// setParameters(): Routine to set parameters and time
// writeParameters(): write to EEPROM and RTC
//-------------------------------------------------------------
void setParameters()
{

  int channel = 0;
  long lastActivity;

  delay(2 * btnDelay);
  lastActivity = millis();

  // Adjust giesstime and switch on/off timer
  while (digitalRead(pinEnterBtn))
  {
    int menuEscapeFlag = 0;
    if (digitalRead(pinUpBtn) == 0)
    {
      giess.time += 60;
      if (timer == OFF)
      {
        menuEscapeFlag = 1;
        if (giess.flag == CTRL_ACT)
        {
          valve[giess.flag].close();
          pump.stop();
          flow.resetFlowMeter();
          giess.flag = CTRL_IDLE;
        }
        else giess.flag = CTRL_ACT; // Manual start of giessing
      }
      lastActivity = millis();
      wdt_reset();
      delay(btnDelay/5);
    }

    if (digitalRead(pinDownBtn) == 0)
    {
      giess.time -= 60;
      lastActivity = millis();
      wdt_reset();
      if (timer == OFF)
        {
          menuEscapeFlag = 1;
          if (giess.flag == CTRL_ACT)
          {
            valve[giess.flag].close();
            pump.stop();
            flow.resetFlowMeter();
            giess.flag = CTRL_IDLE;
          }
          else giess.flag = CTRL_ACT; // Manual start of giessing
        }
      delay(btnDelay/5);
    }

    if (digitalRead(pinManualBtn) == 0)
    {
      lastActivity = millis();
      wdt_reset();
      if (timer) timer = OFF; else timer = ON;
      delay(btnDelay);
    }

    statusDisplay(-2, -1);  // Update display

    // If not button was pressed for 5s save changes and return
    if (millis() - lastActivity > 5000 || menuEscapeFlag == 1)
    {
      writeParameters();
      return;
    }
    wdt_reset();
  }

  delay(btnDelay);
  lastActivity = millis();
  wdt_reset();

  // Set target volumes
  while (channel < CHANNEL)
  {
    // Enter menu
    if (digitalRead(pinEnterBtn) == 0)
    {
      channel++;
      delay(btnDelay);
      lastActivity = millis();
      wdt_reset();
    }

    // Enter manual mode
    if (digitalRead(pinManualBtn) == 0 && (giess.flag == CTRL_IDLE))
    {
      manualGiess(channel);
      lastActivity = millis();
      wdt_reset();
    }

    // Increase volume
    if (digitalRead(pinUpBtn) == 0)
    {
      valve[channel].incVolumeTarget(1);
      statusDisplay(-2, channel);
      delay(btnDelay);
      lastActivity = millis();
      wdt_reset();
    }

    // Decrease volume
    if (digitalRead(pinDownBtn) == 0)
    {
      valve[channel].incVolumeTarget(-1);
      statusDisplay(-2, channel);
      delay(btnDelay);
      lastActivity = millis();
      wdt_reset();
    }

    statusDisplay(-2, channel);  // Update display

    // If not button was pressed for 5s save changes and return
    if (millis() - lastActivity > 5000)
    {
      writeParameters();
      return;
    }
    wdt_reset();
  }

  delay(btnDelay);
  lastActivity = millis();

  // Set ThermoCoeff
  while (digitalRead(pinEnterBtn))
  {
    if (digitalRead(pinUpBtn) == 0)
    {
      thermo.IncTempCoeff(0.1);
      lastActivity = millis();
      wdt_reset();
      delay(btnDelay/5);
    }

    if (digitalRead(pinDownBtn) == 0)
    {
      thermo.IncTempCoeff(-0.1);
      lastActivity = millis();
      wdt_reset();
      delay(btnDelay/5);
    }

    statusDisplay(-2, -3);   // Update display

    // If not button was pressed for 5s save changes and return
    if (millis() - lastActivity > 5000)
    {
      writeParameters();
      return;
    }
    wdt_reset();
  }

  delay(btnDelay);
  lastActivity = millis();
  wdt_reset();

  // Set Daytime
  while (digitalRead(pinEnterBtn))
  {
    if (digitalRead(pinUpBtn) == 0)
    {
      adjustTime(60);  // Function of time library adds seconds
      delay(btnDelay/5);
      lastActivity = millis();
      wdt_reset();
    }

    if (digitalRead(pinDownBtn) == 0)
    {
      adjustTime(-60);  // Function of time library adds seconds
      delay(btnDelay/5);
      lastActivity = millis();
      wdt_reset();
    }

    statusDisplay(-2, -2); // Update display

    // If not button was pressed for 5s save changes and return
    if (millis() - lastActivity > 5000)
    {
      writeParameters();
      return;
    }
    wdt_reset();
  }

  // If Enter button was pressed during daytime setting
  delay(2*btnDelay);
  wdt_reset();
  writeParameters();
}


void writeParameters()
{
  // Write new giessTime to EEPROM
  int eeAdress = 0;
  EEPROM.put(eeAdress, giess.time);
  eeAdress += (sizeof(time_t) + sizeof(int));

  // Write new TempCoeff to EEPROM
  EEPROM.put(eeAdress, thermo.GetTempCoeff());
  eeAdress += sizeof(float);

  // Write new volume targets to EEPROM
  int i;
  for (i = 0; i < CHANNEL; i++)
  {
    EEPROM.put(eeAdress, valve[i].readVolumeTarget());
    eeAdress += sizeof(int);
  }

  // Write new daytime to RTC
  RTC.set(now());

  // Show normal display
  statusDisplay(CTRL_IDLE, -1);
  wdt_reset();
}


//---------------------------------------------------------------------
//---------------------------------------------------------------------
// INTERUPT HANDLER for RTC alarm
//---------------------------------------------------------------------
void btnInterruptSleep(void) // Back from sleep
{
  alarmIsrWasCalled = true;
}
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

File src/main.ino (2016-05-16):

/***********************************************
*   Tomatron v0.1
***********************************************/

#include <Arduino.h>
#include "5110.h"
#include <EEPROM.h>
#include <WIRE.h>       // I2C-Library für RTC-Uhr (z.B. D3231)

#define CHANNEL 3  //Anzahl Wasserkanäle

const byte pulsePin = 2;

int giessen = -1;

class Flowmeter {
  private:
    int calibrationFactor;  // Calibration factor for flow-meter = (Pulses / Liter)
    int pulseCount;
  public:
    static int flag;
    void setCalibrationFactor(int);
    int getPulseCount();
    void resetFlowMeter(void);
    int getVolume(void);
    void pulse();
} flow;

enum flowStatus {IDLE, BUSY};
int Flowmeter::flag = IDLE;

void Flowmeter::setCalibrationFactor(int cf) {
  calibrationFactor = cf;
  EEPROM.put(0, calibrationFactor);
}

int Flowmeter::getPulseCount() {
  return pulseCount;
}

void Flowmeter::resetFlowMeter() {
  pulseCount = 0;
  flag = IDLE;
}

int Flowmeter::getVolume() {
  return (pulseCount / calibrationFactor);
}

void Flowmeter::pulse() {
  pulseCount++;
}

class Magnetvalves {
  private:
    int pin;
    int targetV;
    int currV;
    char plant[10];
  public:
    void setVolumeTarget(int v);
    int readVolumeTarget(void);
    char * getPlant(void);
    int getPin(void);
    int dosing(void);
    int dosing(int);
    int getCurrentVolume(void);
}  valve[CHANNEL];

void Magnetvalves::setVolumeTarget(int v) {
  targetV = v;
}

int Magnetvalves::readVolumeTarget() {
  return targetV;
}

char * Magnetvalves::getPlant() {
  return plant;
}

int Magnetvalves::getPin() {
  return pin;
}

int Magnetvalves::dosing(void) {
  if (flow.flag == IDLE) {
    flow.resetFlowMeter();
    digitalWrite(this->pin, HIGH);
    flow.flag = BUSY;
    return 1;
  } else {
    return 2;
  }

  if (flow.getVolume() < this->targetV) {
    return 0;
  } else
  {
    digitalWrite(this->pin, LOW);
    flow.flag = IDLE;
    return 1;
  }
}


int Magnetvalves::dosing(int vol) {
  if (flow.flag == IDLE) {
    flow.resetFlowMeter();
    digitalWrite(this->pin, HIGH);
    flow.flag = BUSY;
    return 0;
  } else {
    return 2;
  }

  if (flow.getVolume() < vol) {
    return 0;
  } else
  {
    digitalWrite(this->pin, LOW);
    flow.flag = IDLE;
    return 1;
  }
}



int Magnetvalves::getCurrentVolume() {
  return flow.getVolume();
}


void setup() {

  /* Setup Display */
  DisplaySetup();

  /* Setup Serial for Debug */
  Serial.begin(9600);
  Serial.println("Starte Setup");


  /*  Konfigurationsdaten aus EEPROM auslesen                       */
  readEeprom();

  /* Pin for flow meter pulse and interrupt */
  pinMode(pulsePin, INPUT_PULLUP);
  attachInterrupt(pulsePin, interuptPulse, FALLING);

}


void loop() {

  if (/* es ist Zeit zum giessen */1) {
    giessen = 0;
  }

  /* Check ob gegossen werden muss */
  if (giessen > -1) {
    if (valve[giessen].dosing() == 1) {
      giessen++;
    }
    statusDisplay();
  }

  /* Check ob alles gegossen */
  if (giessen == CHANNEL+1) {
    giessen = -1;
  }



}


void DisplaySetup() {
  display.begin(); // init done
  display.setContrast(50); // you can change the contrast around to adapt the display for the best viewing!
  display.setTextSize(1);
  display.setTextColor(BLACK);
  display.setCursor(0,0);
  display.display(); // show splashscreen
  delay(1000);
  display.clearDisplay();   // clears the screen and buffer
  display.display();
}

int readEeprom() {
  int vol;
  int cf;
  int eeAdress = 0;

  EEPROM.get(eeAdress, cf);  // Load calibration factor
  flow.setCalibrationFactor(cf);

  eeAdress = sizeof(int);
  for (byte i = 0; i < (CHANNEL); i++) {
    EEPROM.get(eeAdress, vol);  //
    valve[i].setVolumeTarget(vol);
    eeAdress += sizeof(int);
  }
  return 0;
}

int writeEeprom(void){
  int eeAdress = 0 + sizeof(int); // "vorspulen" nach calibration factor
  for (int i = 0; i < CHANNEL; i++) {
    EEPROM.put(eeAdress, valve[i].readVolumeTarget());
    eeAdress += sizeof(int);
  }
  eeAdress = 0;
  return 0;
}


/***********  Flow-Meter Calibration  **********/

void calibration() {
  float cf;
  float exactAmount = 10;

  display.clearDisplay();
  display.print("Tomatron v0.1   "); display.println("Calibration");
  display.println();
  display.println("Nach Tastendruck laufen");
  display.println("ca. 10L Wasser aus Schlauch 1.");
  display.println("Genaue Menge auswiegen!");
  display.display(); // show screen


  while (!valve[0].dosing(10)) {
  //  calibrationDisplay(valve[0].getCurrentVolume());
  }


  // Einstellung exakteMenge über Up/Down-Taster, Bestätigung durch Enter
  calibrationDisplay(exactAmount);
  while (digitalRead(4)) {

    if (digitalRead(5)) {	// wenn Arduino-Pin 6 auf LOW -> Einstell-Taste gedrückt
      exactAmount += 0.1;
      calibrationDisplay(exactAmount);
      delay(200);
    }

    if (digitalRead(6)) {
      exactAmount -= 0.1;
      calibrationDisplay(exactAmount);
      delay(200);
    }
  }

  // Berechnung Kalibrierfaktor und speichern im EEPROM *
  cf = flow.getPulseCount() / exactAmount;
  flow.setCalibrationFactor(cf);
}

void calibrationDisplay(float menge) {

  display.clearDisplay();
  display.setCursor(0,0);
  display.println("Mit Up/Down-Tasten");
  display.println("exakte Menge einstellen");
  display.println("");
  display.setTextSize(2);
  display.print(menge); display.println(" L");
  display.setTextSize(1);
  display.display();

}


/***********  Loop Routines  **********/
void statusDisplay() {

  display.clearDisplay();

  display.print("Tomatron v0.1   "); display.println("xx:xx"); //Uhrzeit
  display.println();

  for (int i = 0; i < CHANNEL; i++) {
    display.print(valve[i].getPlant()); display.print(valve[i].readVolumeTarget());
    display.print(" "); display.println(valve[i].getCurrentVolume());
  }

  display.display(); // show screen
}


void interuptPulse() {
  flow.pulse();
}

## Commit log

2016-05-15 Added classes for valves and flowmeter
2016-05-26 target set and read fixed
    [main.cpp]
2016-05-26 fixed interrupt
2016-05-26 calibration routine not fully fixed
    [main.cpp]
2016-05-26 calibration fixed
2016-05-28 added clock and timer set to volume set routine
2016-05-29 added pump and switched display to software SPI
2016-05-29 added pump start/stop to calibration
2016-06-13 SPI lib removed
2016-06-14 Sleep interrupted by WDT and external interrupt
2016-07-02 test flow meter works
2016-09-16 Hardware folder added
    [SubD-Belegung.ods, subd.brd, subd.sch]
2016-10-03 added powerpack.sch
    [powerpack.sch]
2016-10-10 Powerpack Eagle File
    [SubD-Belegung.ods, powerpack.brd, powerpack.sch]
2016-10-27 Version 1.0
    [SubD-Belegung.ods, powerpack.brd, powerpack.sch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]
2017-04-06 Timer on/off
